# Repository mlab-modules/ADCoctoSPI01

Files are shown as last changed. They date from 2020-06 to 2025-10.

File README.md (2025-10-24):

# ADCoctoSPI01 - Octal Input High-Speed ADC Module

The ADCoctoSPI01 is an eight-channel, high-speed analog-to-digital conversion module designed for signal acquisition in imaging and similar high-speed applications. It integrates a Texas Instruments AFE5801 analog front-end (AFE), which combines eight variable-gain amplifiers (VGAs) and eight 12-bit ADCs with a sampling rate up to 65 MSPS. Data output is serialized through an LVDS interface.

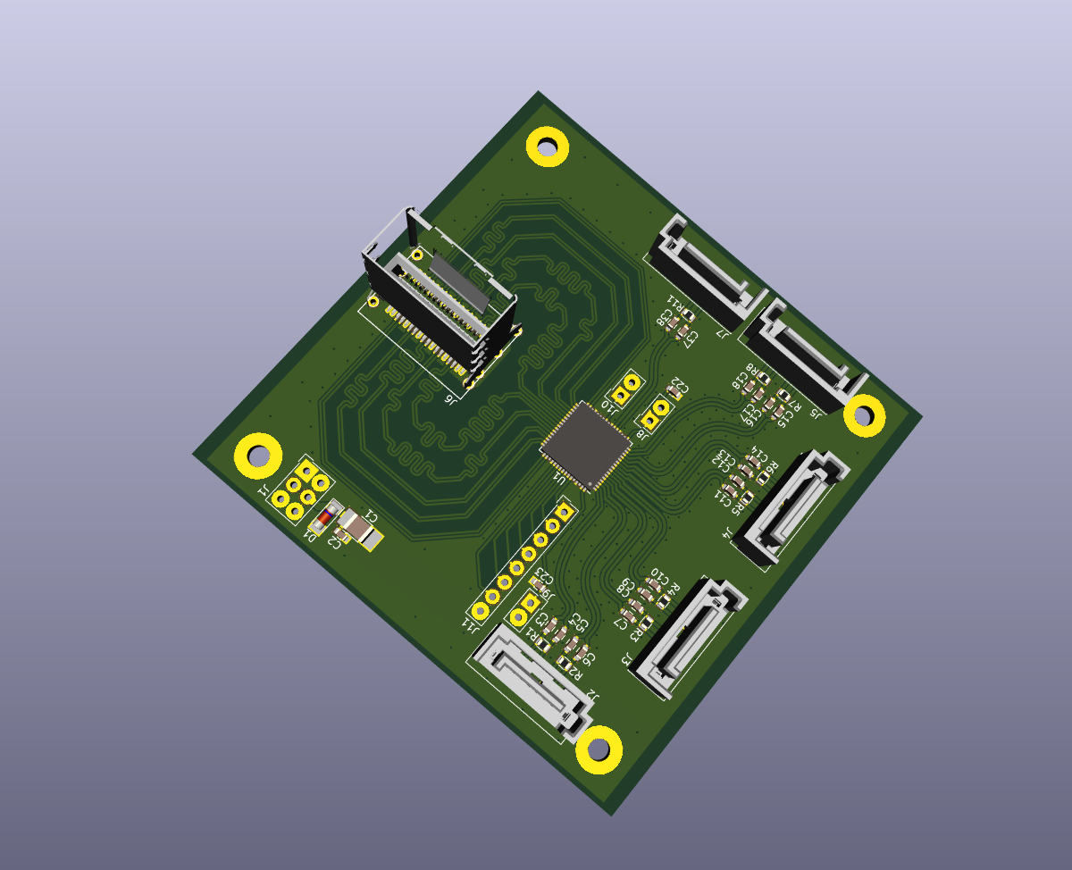
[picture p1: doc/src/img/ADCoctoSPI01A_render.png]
ADCoctoSPI01A


This module is ideally used in combination with the [MPPB01 baseboard for Parallella](https://www.mlab.cz/module/MPPB01/), which features a compatible miniSAS connector, allowing for direct integration and high-speed data transfer.

## Features

* **8 differential analog input channels**
* **Integrated AFE5801 from Texas Instruments**
  * 8x VGAs with -5 dB to 31 dB gain range
  * 8x 12-bit ADCs, up to 65 MSPS sampling rate
  * Integrated anti-aliasing filter (7.5 / 10 / 14 MHz selectable)
  * Serial LVDS output
  * SPI control interface
* **MiniSAS (SFF-8087) connector for LVDS data output**
* **Separate SPI interface for configuration and diagnostics**
* **On-board linear regulators for 1.8V and 3.3V supplies**
* **Operating voltage: 3.6 V to 5.4 V**
* **Operating temperature: -20 °C to +40 °C**

## Technical Specifications

| Parameter | Value | Description |
| --- | --- | --- |
| ADC Resolution | 12 bits | Per channel |
| Number of Channels | 8 | Differential |
| Max Sampling Rate | 65 MSPS | Per channel |
| Input Voltage Swing | 2 Vpp | Differential, max linear input range |
| VGA Gain Range | -5 dB to +31 dB | Step size: 0.125/1 dB |
| Input Referred Noise | 5.5 nV/√Hz | At VGA gain = 31 dB |
| Signal-to-Noise Ratio (SNR) | ~65 dBFS | Typical at 65 MSPS, -1 dBFS input |
| Total Harmonic Distortion (THD) | -65 dBFS | At 5 MHz input, max gain |
| Signal-to-Noise and Distortion Ratio (SINAD) | ~68 dB | |
| Antialias Filter Cutoff | 7.5 / 10 / 14 MHz | Programmable |
| Common-Mode Input Voltage (VCM) | 1.6 V | Recommended bias for AC coupling |
| Input Capacitance | 2 pF | Differential input |
| Input Resistance | 5 kΩ | To internal bias |

## Connectors

* **J1-J4**: Differential analog inputs (IN1P/M to IN8P/M) (SATA connectors)
* **J10A**: MiniSAS connector for serialized LVDS data (D1-D8, FCLK, DCLK)
* **J8**: SPI control interface (SCLK, SDATA, SDOUT, SEN, RESET, SYNC)
* **J11**: Power input (+5V, GND)

## Power Supply

* Requires a single 5V power supply.
* Onboard regulators generate 3.3V and 1.8V for AFE operation.

## AFE5801 Configuration Highlights

* **Gain Control**: SPI-controlled VGA gain, from -5 dB to 31 dB in 0.125 dB or 1 dB steps
* **Clamping and Filtering**: Optional signal clamping and integrated third-order low-pass filter
* **Sampling Clock**: Differential clock input (LVDS/PECL supported)
* **LVDS Output**: Serialized outputs for each channel (D1-D8), frame clock (FCLK), and data clock (DCLK)

## Typical Applications

* Medical ultrasound systems
* Non-destructive testing
* High-speed data acquisition
* Multichannel signal digitization in SDR receivers

## References

* [AFE5801 Datasheet](https://www.ti.com/product/AFE5801)
* Other compatible AFEs: AFE5805, AFE5809 (with differing performance and power specs)

## Notes

* Only the AFE5801 is populated by default; board supports footprint-compatible variants (AFE5803, AFE5804 etc.).
* For optimal performance, ensure proper analog signal termination and impedance matching on all differential inputs.
* Follow ESD precautions during handling.

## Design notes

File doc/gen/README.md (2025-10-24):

# PCB

Board size: 70.61x70.61 mm (2.78x2.78 inches)

- This is the size of the rectangle that contains the board
- Thickness: 1.6 mm (63 mils)
- Material: FR4
- Finish: None
- Layers: 2
- Copper thickness: 35 µm

Solder mask: TOP / BOTTOM

- Color: Green

Silk screen: TOP / BOTTOM

- Color: White

Stackup:

| Name | Type | Color | Thickness [µm]| Material | Er | Loss tan |
|---|---|---|---|---|---|---|
| F.SilkS | Top Silk Screen | | | | | |
| F.Paste | Top Solder Paste | | | | | |
| F.Mask | Top Solder Mask | | 10 | | | |
| F.Cu | copper | | 35 | | | |
| dielectric 1 | core | | 1510 | FR4 | 4.5 | 0.020 |
| B.Cu | copper | | 35 | | | |
| B.Mask | Bottom Solder Mask | | 10 | | | |
| B.Paste | Bottom Solder Paste  | | | | | |
| B.SilkS | Bottom Silk Screen | | | | | |

# Important sizes

Clearance: 0.2 mm (8 mils)

Track width: 0.2 mm (8 mils)

- By design rules: 0.15 mm (6 mils)

Drill: 0.3 mm (12 mils)

- Vias: 0.5 mm (20 mils) [Design: 0.3 mm (12 mils)]
- Pads: 0.3 mm (12 mils)
- The above values are real drill sizes, they add 0.1 mm (4 mils) to plated holes (PTH)

Via: 0.75/0.4 mm (30/16 mils)

- By design rules: 0.4/0.2 mm (16/8 mils)
- Micro via: yes [0.2/0.1 mm (8/4 mils)]
- Buried/blind via: yes
- Total: 263 (thru: 263 buried/blind: 0 micro: 0)

Outer Annular Ring: 0.05 mm (2 mils)

- By design rules: 0.05 mm (2 mils)

Eurocircuits class: 6F
- Using min drill 0.15 mm for an OAR of 0.13 mm

# General stats

Components count: (SMD/THT)

- Top: 38/14 (SMD + THT)
- Bottom: 27/0 (SMD)

Defined tracks:

- 0.2 mm (8 mils)
- 0.3 mm (12 mils)
- 0.4 mm (16 mils)
- 0.5 mm (20 mils)
- 1.0 mm (39 mils)

Used tracks:

- 0.2 mm (8 mils) (10) defined: yes
- 0.25 mm (10 mils) (3) defined: no
- 0.28 mm (11 mils) (2504) defined: no
- 0.3 mm (12 mils) (167) defined: yes
- 0.4 mm (16 mils) (662) defined: yes
- 0.5 mm (20 mils) (45) defined: yes
- 0.8 mm (31 mils) (7) defined: no
- 1.0 mm (39 mils) (15) defined: yes

Defined vias:

Used vias:

- 0.75/0.4 mm (30/16 mils) (Count: 229, Aspect: 2.1 A) defined: no
- 0.8/0.4 mm (31/16 mils) (Count: 34, Aspect: 2.0 A) defined: no

Holes (excluding vias):

- 0.2 mm (8 mils) (45)
- 0.74 mm (29 mils) (35)
- 0.8 mm (31 mils) (8)
- 0.89 mm (35 mils) (20)
- 1.35 mm (53 mils) (10)
- 1.55 mm (61 mils) (2)
- 3.0 mm (118 mils) (4)

Oval holes:

Drill tools (including vias and computing adjusts and rounding):

- 0.3 mm (12 mils) (45)
- 0.5 mm (20 mils) (263)
- 0.85 mm (33 mils) (35)
- 0.9 mm (35 mils) (8)
- 1.0 mm (39 mils) (20)
- 1.45 mm (57 mils) (10)
- 1.55 mm (61 mils) (2)
- 3.1 mm (122 mils) (4)

Solder paste stats:

Using a paste with 87.75 % alloy, that has an specific gravity for the alloy of 7.4 g/cm³
and 1.0 g/cm³ for the flux. This paste has an specific gravity of  4.15 g/cm³.

The stencil thickness is  0.12 mm.

| Side | Pads with paste | Area [mm²] | Paste [g] |
|---|---|---|---|
| Top | 172 | 104.12 | 0.52 |
| Bottom | 58 | 77.69 | 0.39 |
| Total  | 230 | 181.81 | 0.90 |

Note: this is just an approximation to the theoretical value. Margins of the solder mask and waste aren't computed.

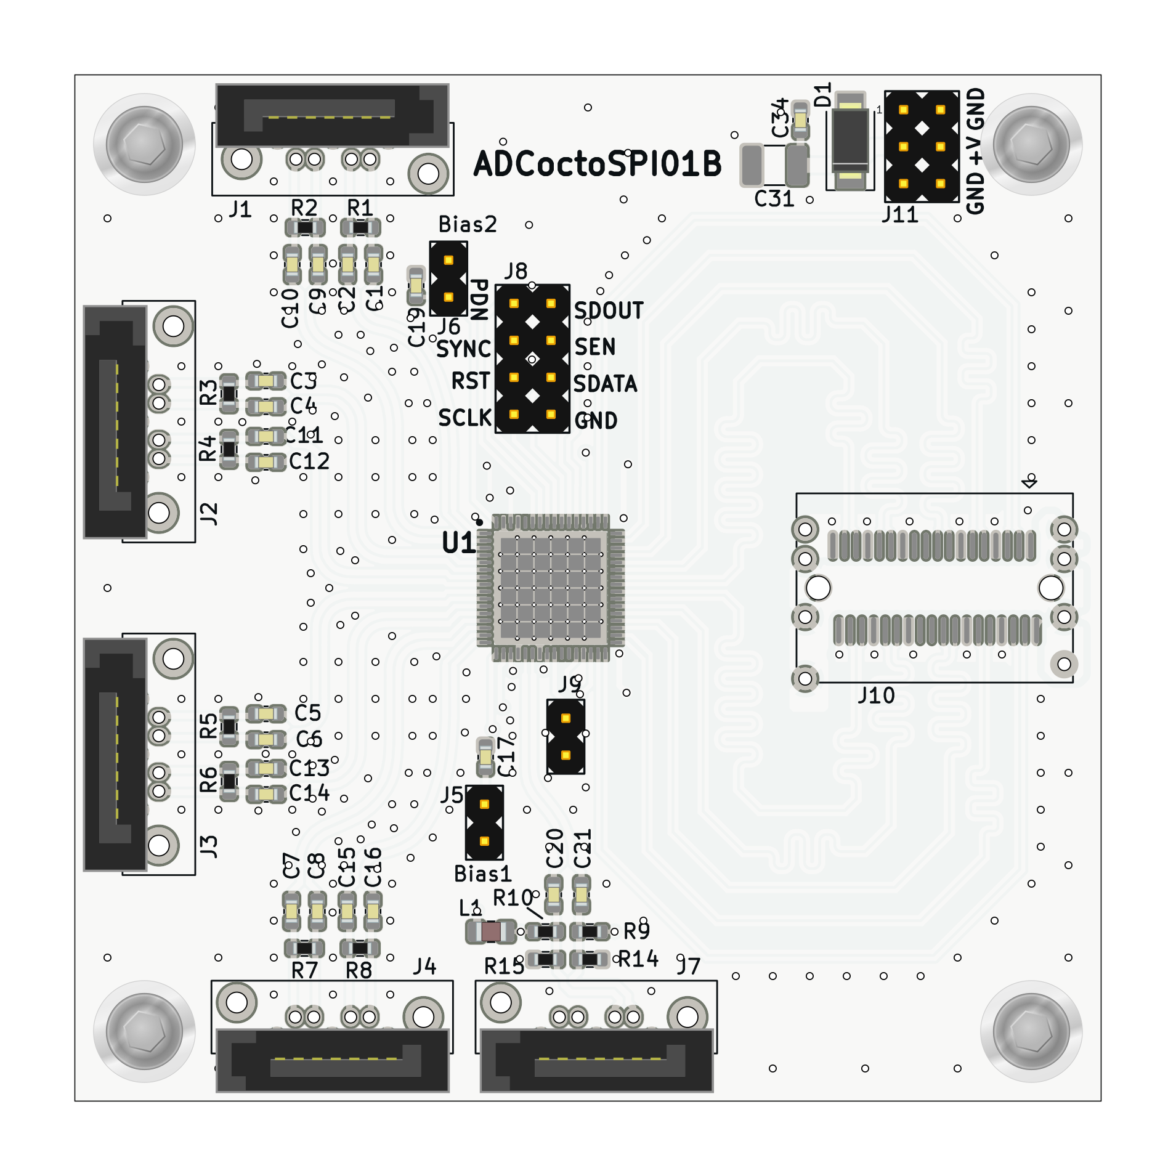
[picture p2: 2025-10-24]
doc/gen/img/ADCoctoSPI01-top.png

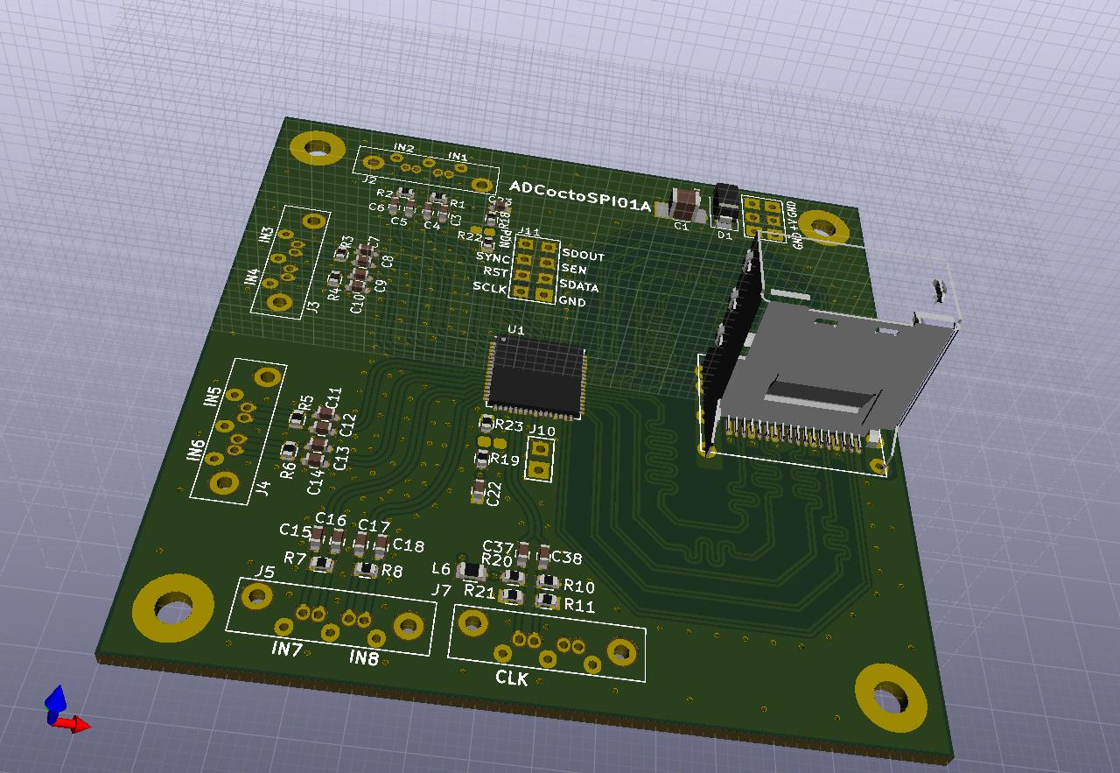
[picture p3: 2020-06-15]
doc/src/img/ADCoctoSPI01A.jpg

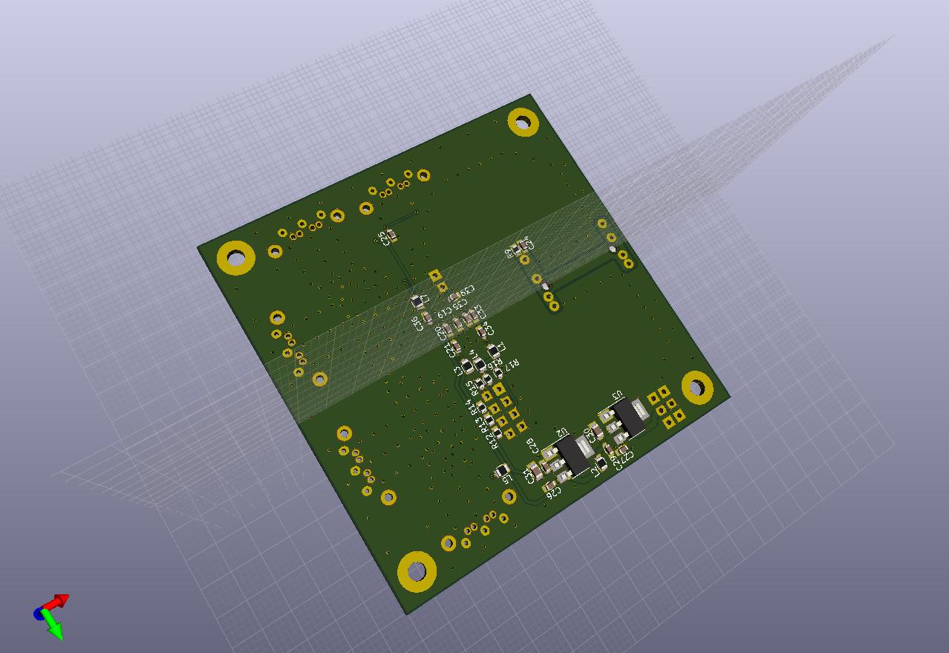
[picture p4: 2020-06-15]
doc/src/img/bottom.jpg

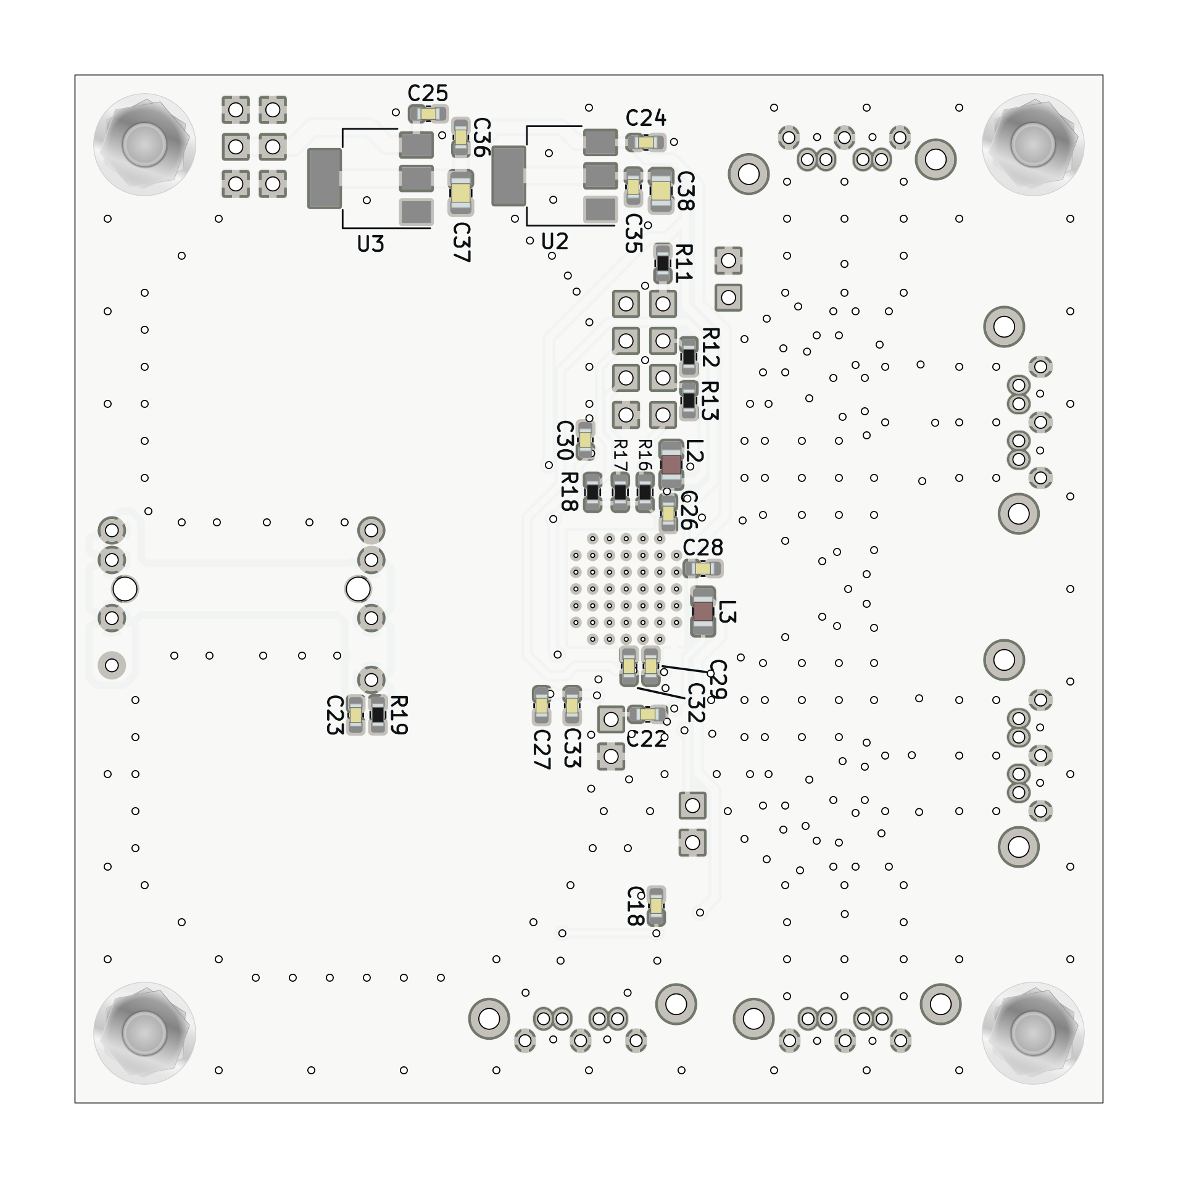
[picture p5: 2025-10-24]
doc/gen/img/ADCoctoSPI01-bottom.png

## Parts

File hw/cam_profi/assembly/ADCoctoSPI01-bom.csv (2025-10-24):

Component | Description | Part | References | Value | Footprint | Quantity Per PCB | Datasheet | ust_id
1 |  | C_Small-device | C1C2C3C4C5C6C7C8C9C10C11C12C13C14C15C16 | 10nF | C_0603_1608Metric | 16 |  | 5c70984812875079b91f8bef
2 |  | C_Small-device | C17C18C19C20C21C22C23C24C25C26C27C28C29C30C32C33C34C35C36 | 100nF | C_0603_1608Metric | 19 |  | 5c70984812875079b91f8bf2
3 |  | C_Small-device | C37C38 | 10uF | C_0805_2012Metric | 2 |  | 5c70984812875079b91f8bbd
4 |  | C_Small-device | C31 | 100uF/6V3 | C_1210_3225Metric_Pad1.33x2.70mm_HandSolder | 1 | https://www.tme.eu/sk/katalog/ | 5c70984812875079b91f8bbb
5 |  | D_Small-device | D1 | M4 | D_SMA | 1 |  | 5c70984512875079b91f88ac
6 |  | HEADER_2x03_PARALLEL-MLAB_HEADER | J11 | +5V | Straight_2x03 | 1
7 |  | HEADER_1x02-MLAB_HEADER | J5J6J9 | HEADER_1x02 | Straight_1x02 | 3
8 |  | HEADER_2x04-MLAB_HEADER | J8 | HEADER_2x04 | Straight_2x04 | 1
9 |  | SAS_mini_1888174-MLAB_CONNECTORS | J10 | SAS_mini_1888174 | SAS-mini_TEConnectivity_1888174_Vertical | 1 |  | 624ede60592c2d62176d5a96
10 |  | SATA7-67491-1030-MLAB_CONNECTORS | J1J2J3J4J7 | SATA7-67491-1030 | SATA-7_THT_VERT_2 | 5 |  | 5c70984712875079b91f8a7b
11 |  | L-device | L1L2L3 | BLM21PG300SN1D | L_0805_2012Metric_Pad1.15x1.40mm_HandSolder | 3 |  | 5c70984412875079b91f87fd
12 |  | R-device | R14R15 | 82 | R_0603_1608Metric | 2 |  | 5c70984512875079b91f8955
13 |  | R-device | R1R2R3R4R5R6R7R8R19 | 100 | R_0603_1608Metric | 9 |  | 5c70984512875079b91f8956
14 |  | R-device | R9R10 | 130 | R_0603_1608Metric | 2 |  | 5cd08b17128750448e4542b1
15 |  | R-device | R11R12R13R16R17R18 | 10k | R_0603_1608Metric | 6 |  | 5c70984512875079b91f8962
16 |  | AFE5801-DENGS_lib | U1 | AFE5801 | VQFN-64_9.15x9.15mm_EP_7.5x7.5mm | 1 | https://www.ti.com/lit/ds/symlink/afe5801.pdf | 624edf21592c2d62176d5abc
17 |  | LD1117S18TR-RESCUE-ADCoctoSPI01A | U2 | LM1117MP-1,8/NO | SOT-223-3_TabPin2 | 1 |  | 5c70984712875079b91f8af6
18 |  | LD1117S33TR-RESCUE-ADCoctoSPI01A | U3 | LM1117MP-3,3/NO | SOT-223-3_TabPin2 | 1 |  | 5c70984712875079b91f8af9

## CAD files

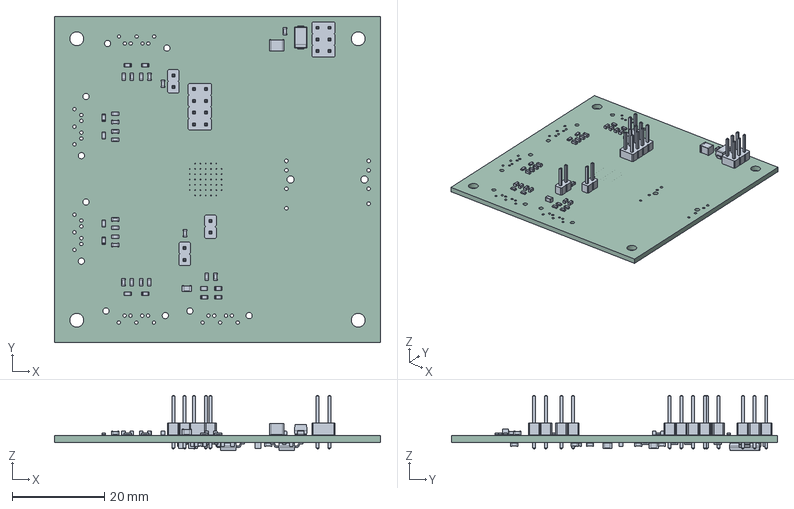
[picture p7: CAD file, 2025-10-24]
doc/gen/ADCoctoSPI01.step
70.6 x 70.6 x 11.9 mm
C_1210_3225Metric
D_SMA
R_0603_1608Metric x 19
C_0603_1608Metric x 35
PinHeader_2x04_P2.54mm_Vertical
PinHeader_1x02_P2.54mm_Vertical x 3
PinHeader_2x03_P2.54mm_Vertical
L_0805_2012Metric x 3
SOT-223 x 2
C_0805_2012Metric x 2
kibot_9znxb3cl_PCB

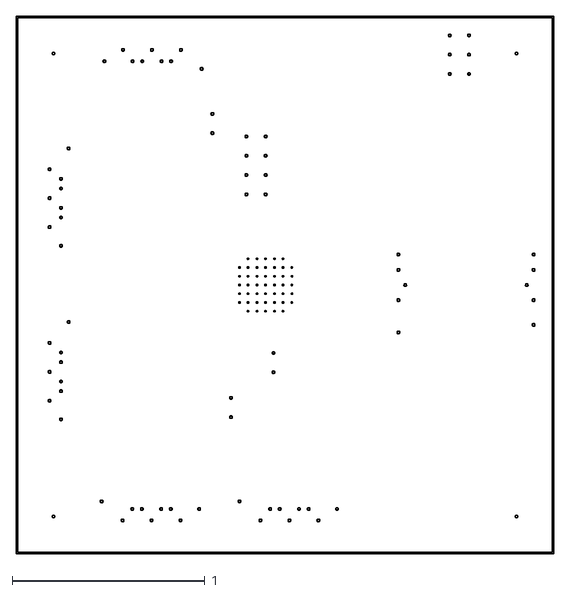
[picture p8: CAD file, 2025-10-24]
doc/gen/dxf/ADCoctoSPI01-Edge_Cuts.dxf
2.79 x 2.79

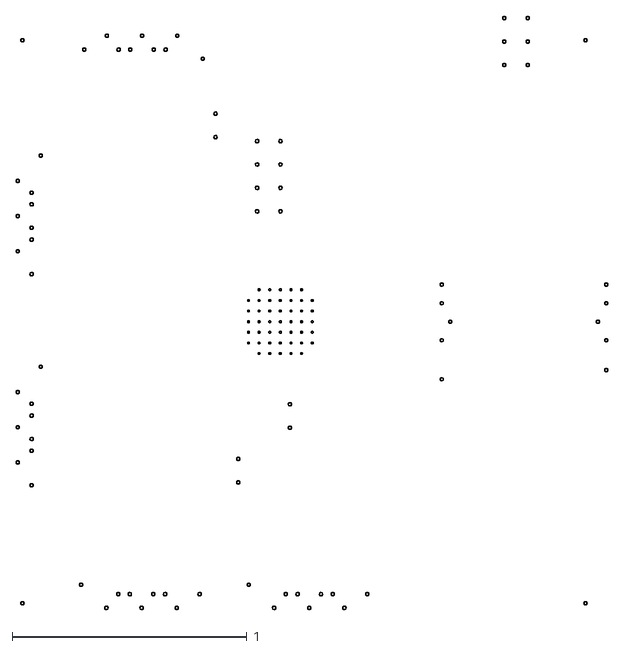
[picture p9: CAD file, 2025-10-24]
doc/gen/dxf/ADCoctoSPI01-User_Eco1.dxf
2.52 x 2.53

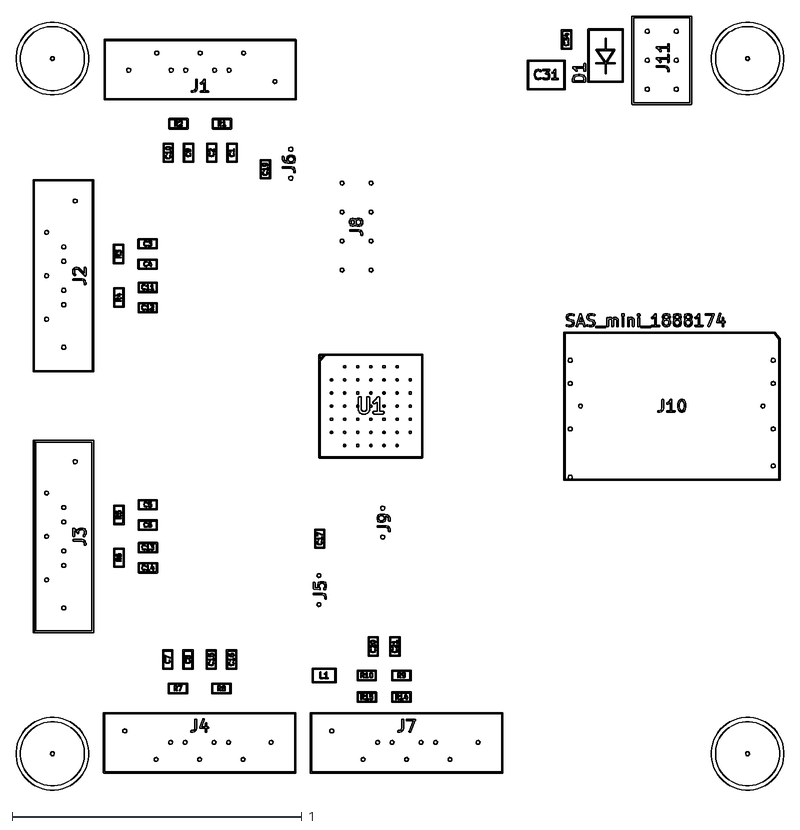
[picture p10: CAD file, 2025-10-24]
doc/gen/dxf/ADCoctoSPI01-F_Fab.dxf
2.65 x 2.67

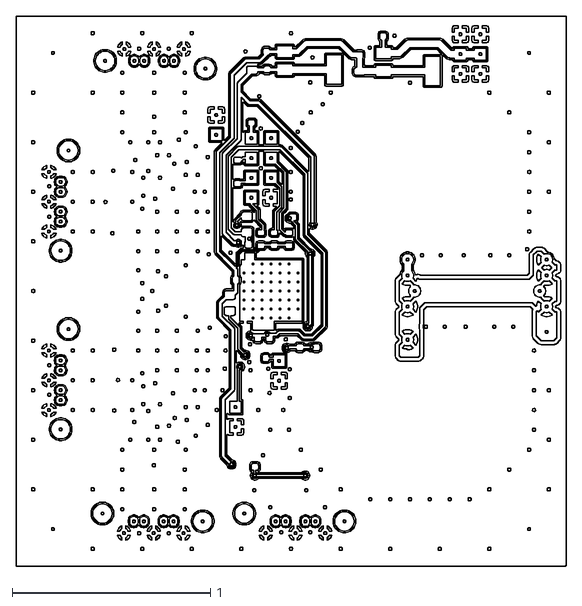
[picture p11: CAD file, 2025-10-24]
doc/gen/dxf/ADCoctoSPI01-B_Cu.dxf
2.77 x 2.77

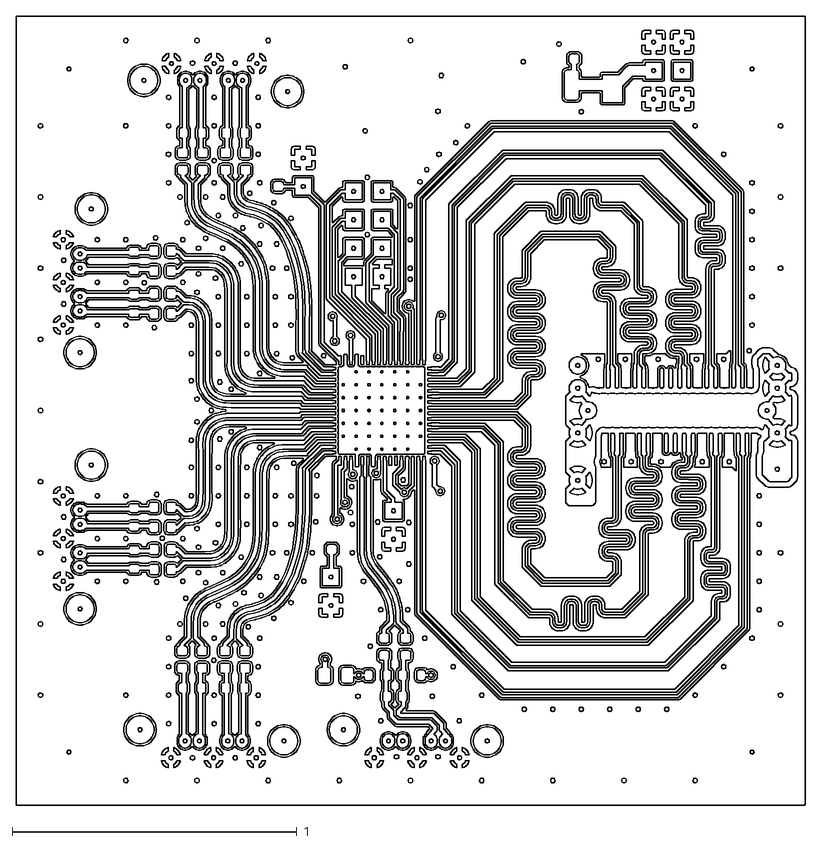
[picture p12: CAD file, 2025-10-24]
doc/gen/dxf/ADCoctoSPI01-F_Cu.dxf
2.77 x 2.77

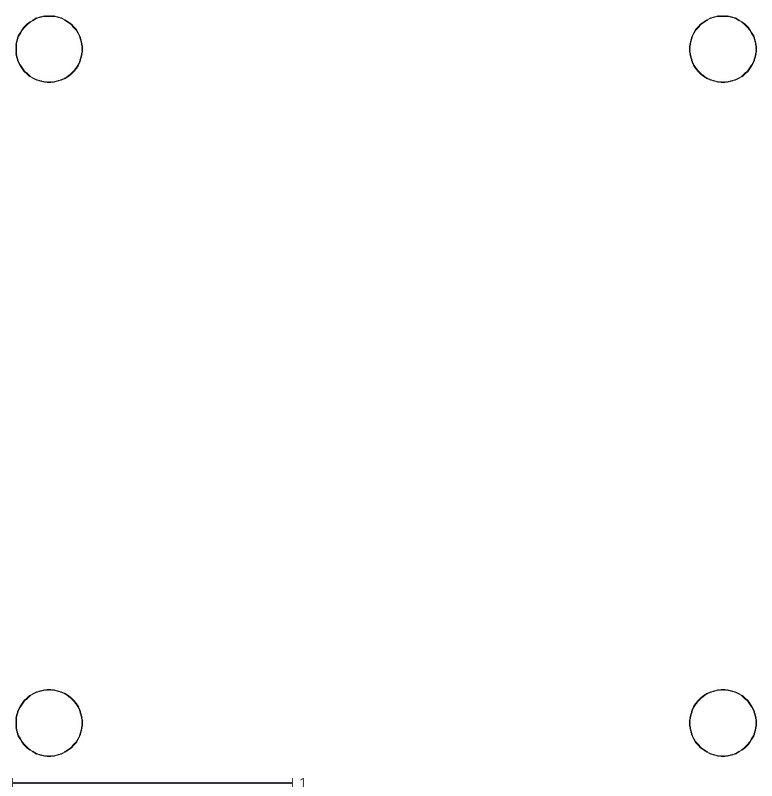
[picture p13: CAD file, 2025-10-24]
doc/gen/dxf/ADCoctoSPI01-B_Adhesive.dxf
2.64 x 2.64

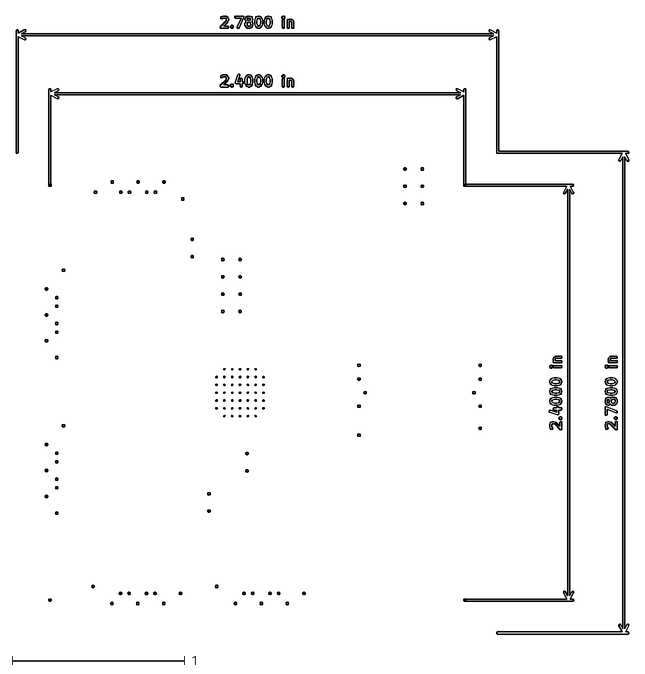
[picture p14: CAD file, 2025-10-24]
doc/gen/dxf/ADCoctoSPI01-User_Drawings.dxf
3.54 x 3.58

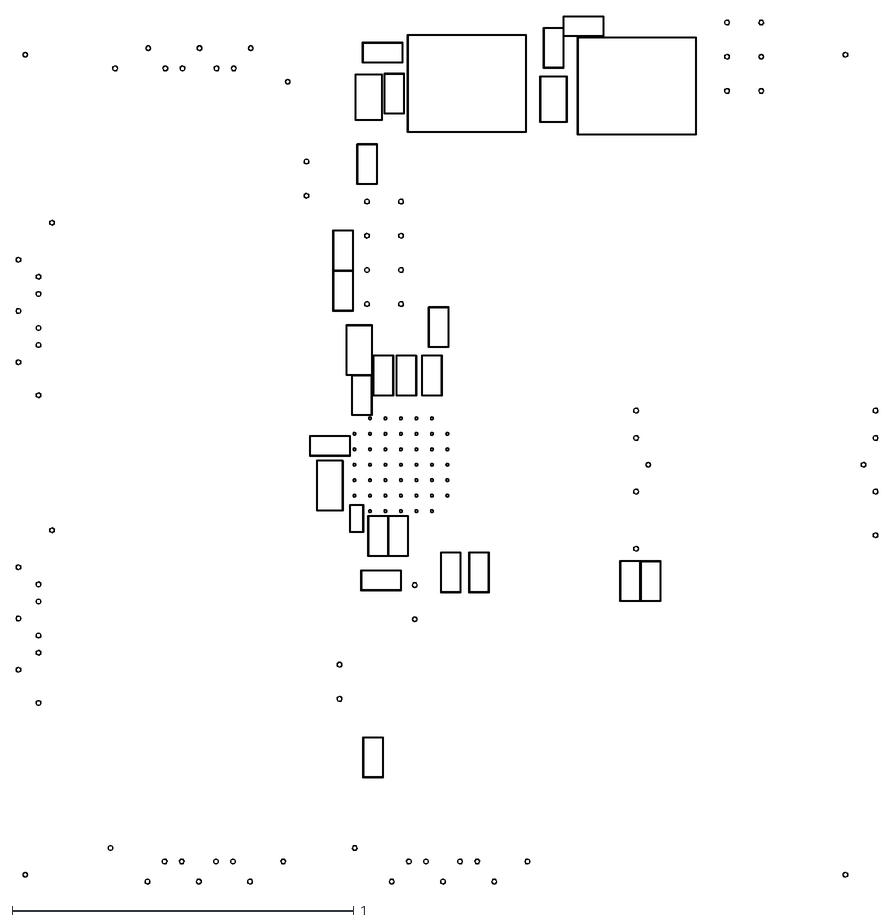
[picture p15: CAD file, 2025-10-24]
doc/gen/dxf/ADCoctoSPI01-B_Courtyard.dxf
2.52 x 2.54

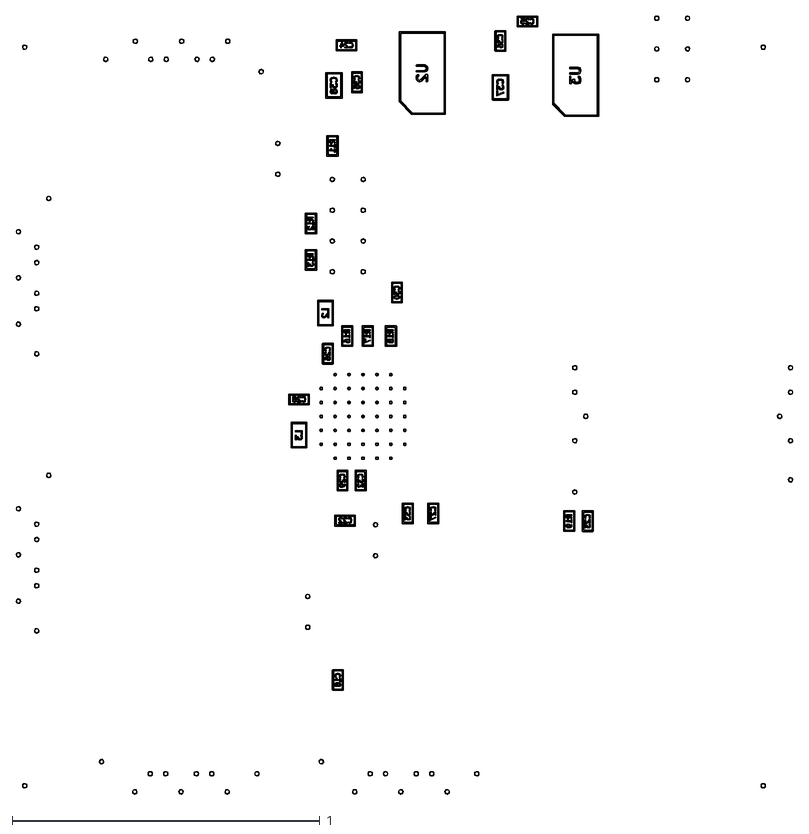
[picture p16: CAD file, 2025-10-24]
doc/gen/dxf/ADCoctoSPI01-B_Fab.dxf
2.52 x 2.53

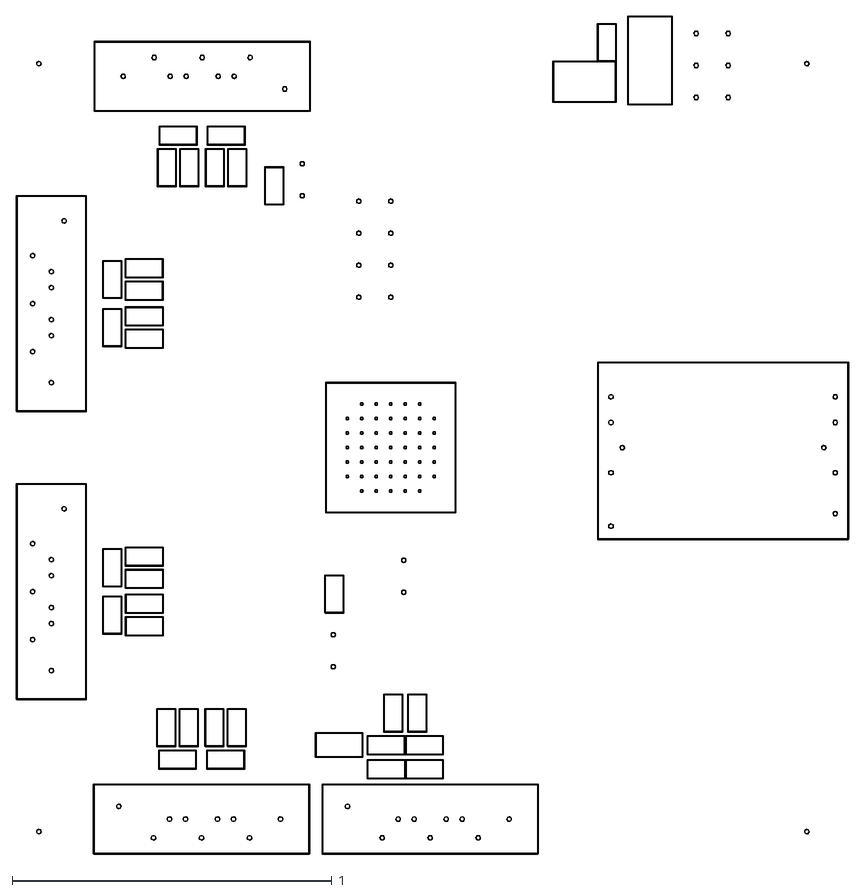
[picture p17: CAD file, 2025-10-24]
doc/gen/dxf/ADCoctoSPI01-F_Courtyard.dxf
2.60 x 2.62

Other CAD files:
doc/gen/dxf/ADCoctoSPI01-B_Mask.dxf
doc/gen/dxf/ADCoctoSPI01-B_Paste.dxf
doc/gen/dxf/ADCoctoSPI01-B_Silkscreen.dxf
doc/gen/dxf/ADCoctoSPI01-F_Mask.dxf
doc/gen/dxf/ADCoctoSPI01-F_Paste.dxf
doc/gen/dxf/ADCoctoSPI01-F_Silkscreen.dxf

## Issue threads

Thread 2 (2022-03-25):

mini-SAS connector alingment

kaklik, 2022-03-25:
Vypadá to, že stejně jako https://github.com/mlab-modules/MPPB01/issues/3 má i tento modul problém se špatně zarovnanými ploškami u mini-SAS konektoru.

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

kaklik, 2022-03-25:
Vyřešeno změnou na KiCAD upstream verzi footprintu a jeho opravou.

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

Closed 2022-03-25.

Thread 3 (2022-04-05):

Wrong footprint of ADC

kaklik, 2022-04-05:
@ChroustJan  přišel na to, že pouzdro pod ADC nerespektuje základní požadavky výrobce na footprint. [viz datasheet strana 46.](https://www.ti.com/lit/ds/symlink/afe5801.pdf)
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

Problém je poměrně zásadní, protože zřjemě zbytečně zvyšuje teplotu a šum ADC.

Společně s tím stávající layout narušuje pravidlo absence jiných signálů než GND přímo pod pouzdrem ADC.

kaklik, 2022-05-25:
Tohle je snad již vyřešené.

Closed 2022-05-25.

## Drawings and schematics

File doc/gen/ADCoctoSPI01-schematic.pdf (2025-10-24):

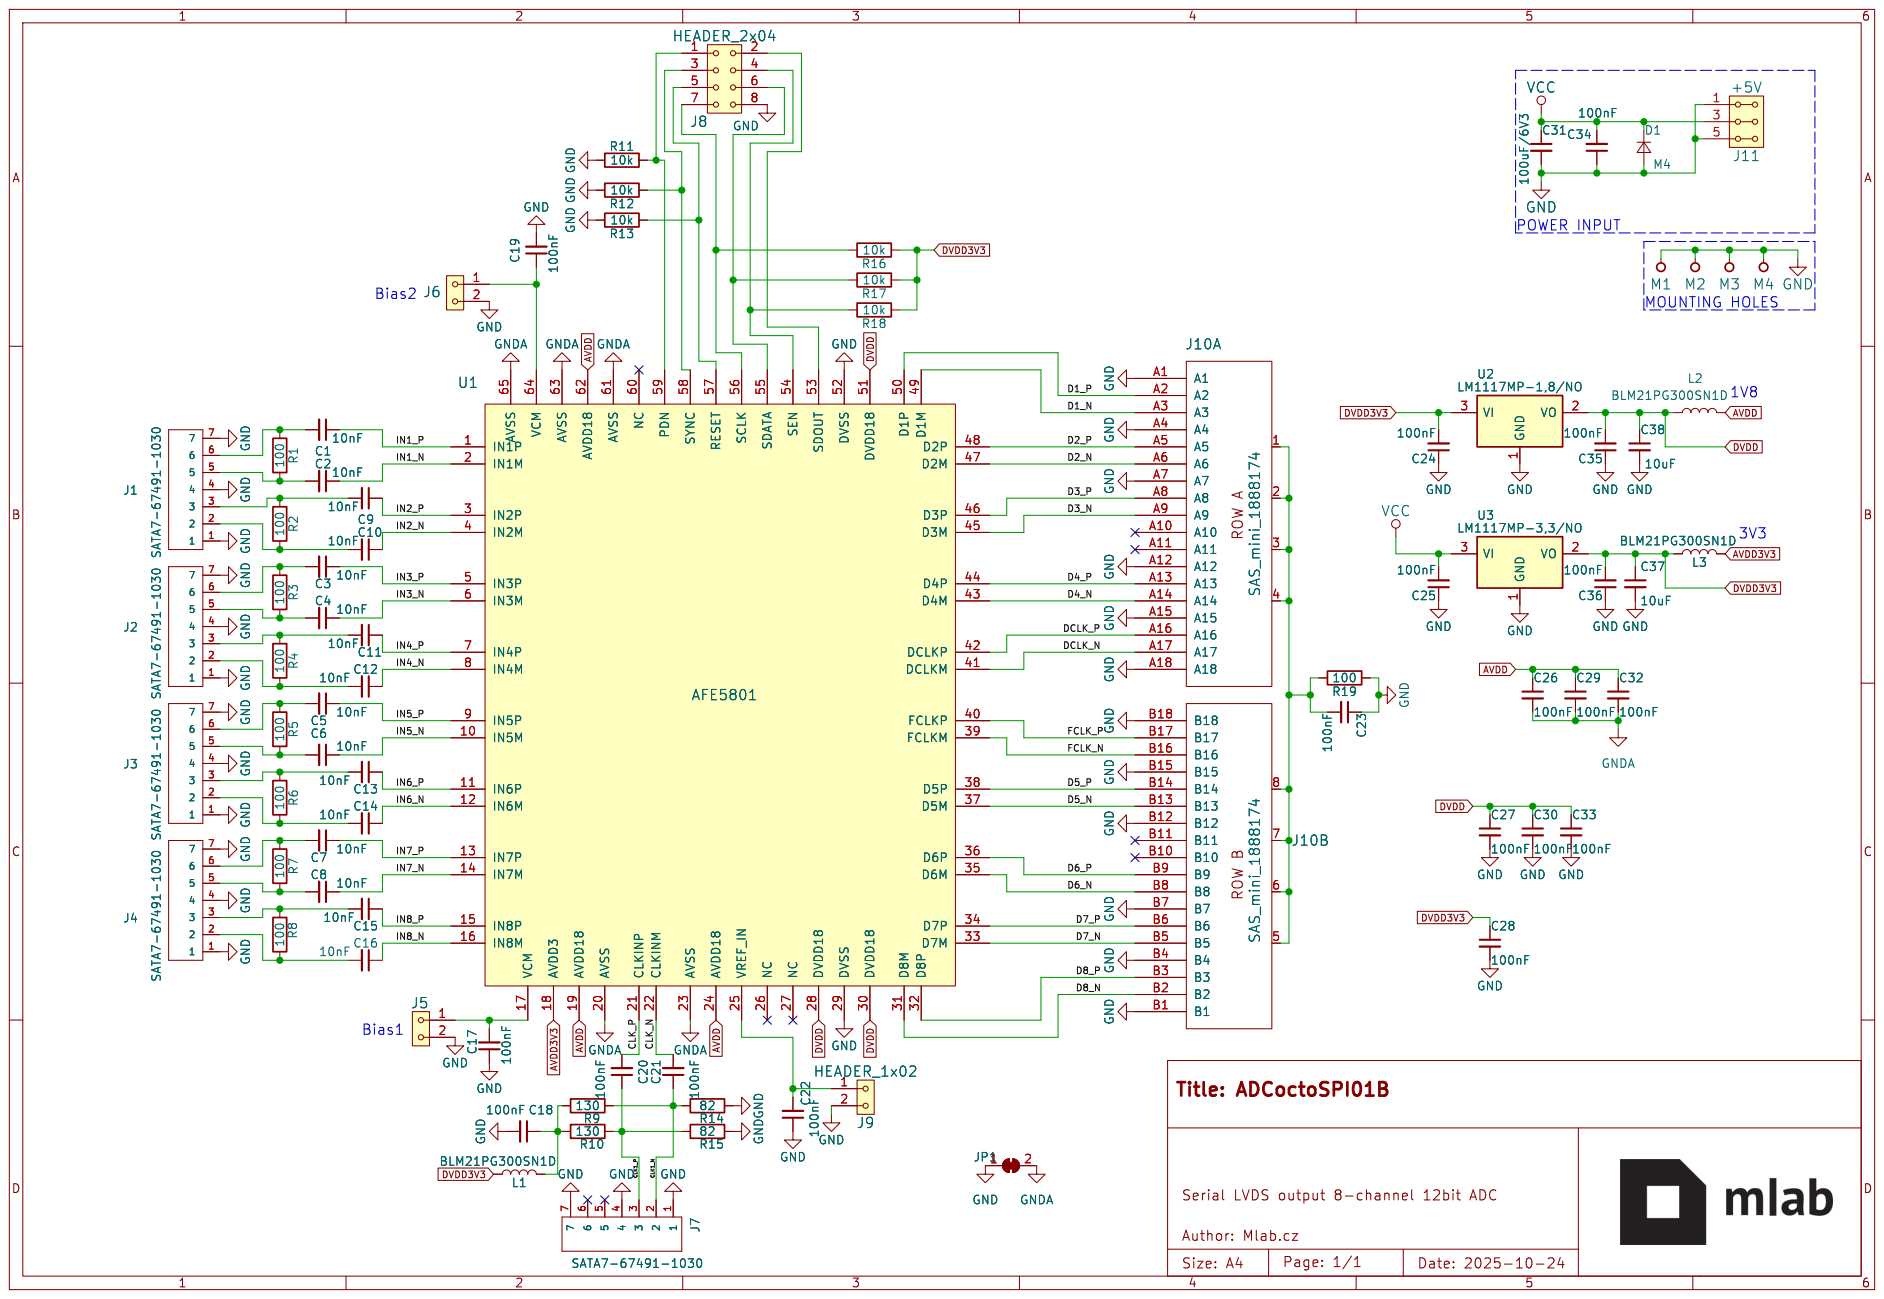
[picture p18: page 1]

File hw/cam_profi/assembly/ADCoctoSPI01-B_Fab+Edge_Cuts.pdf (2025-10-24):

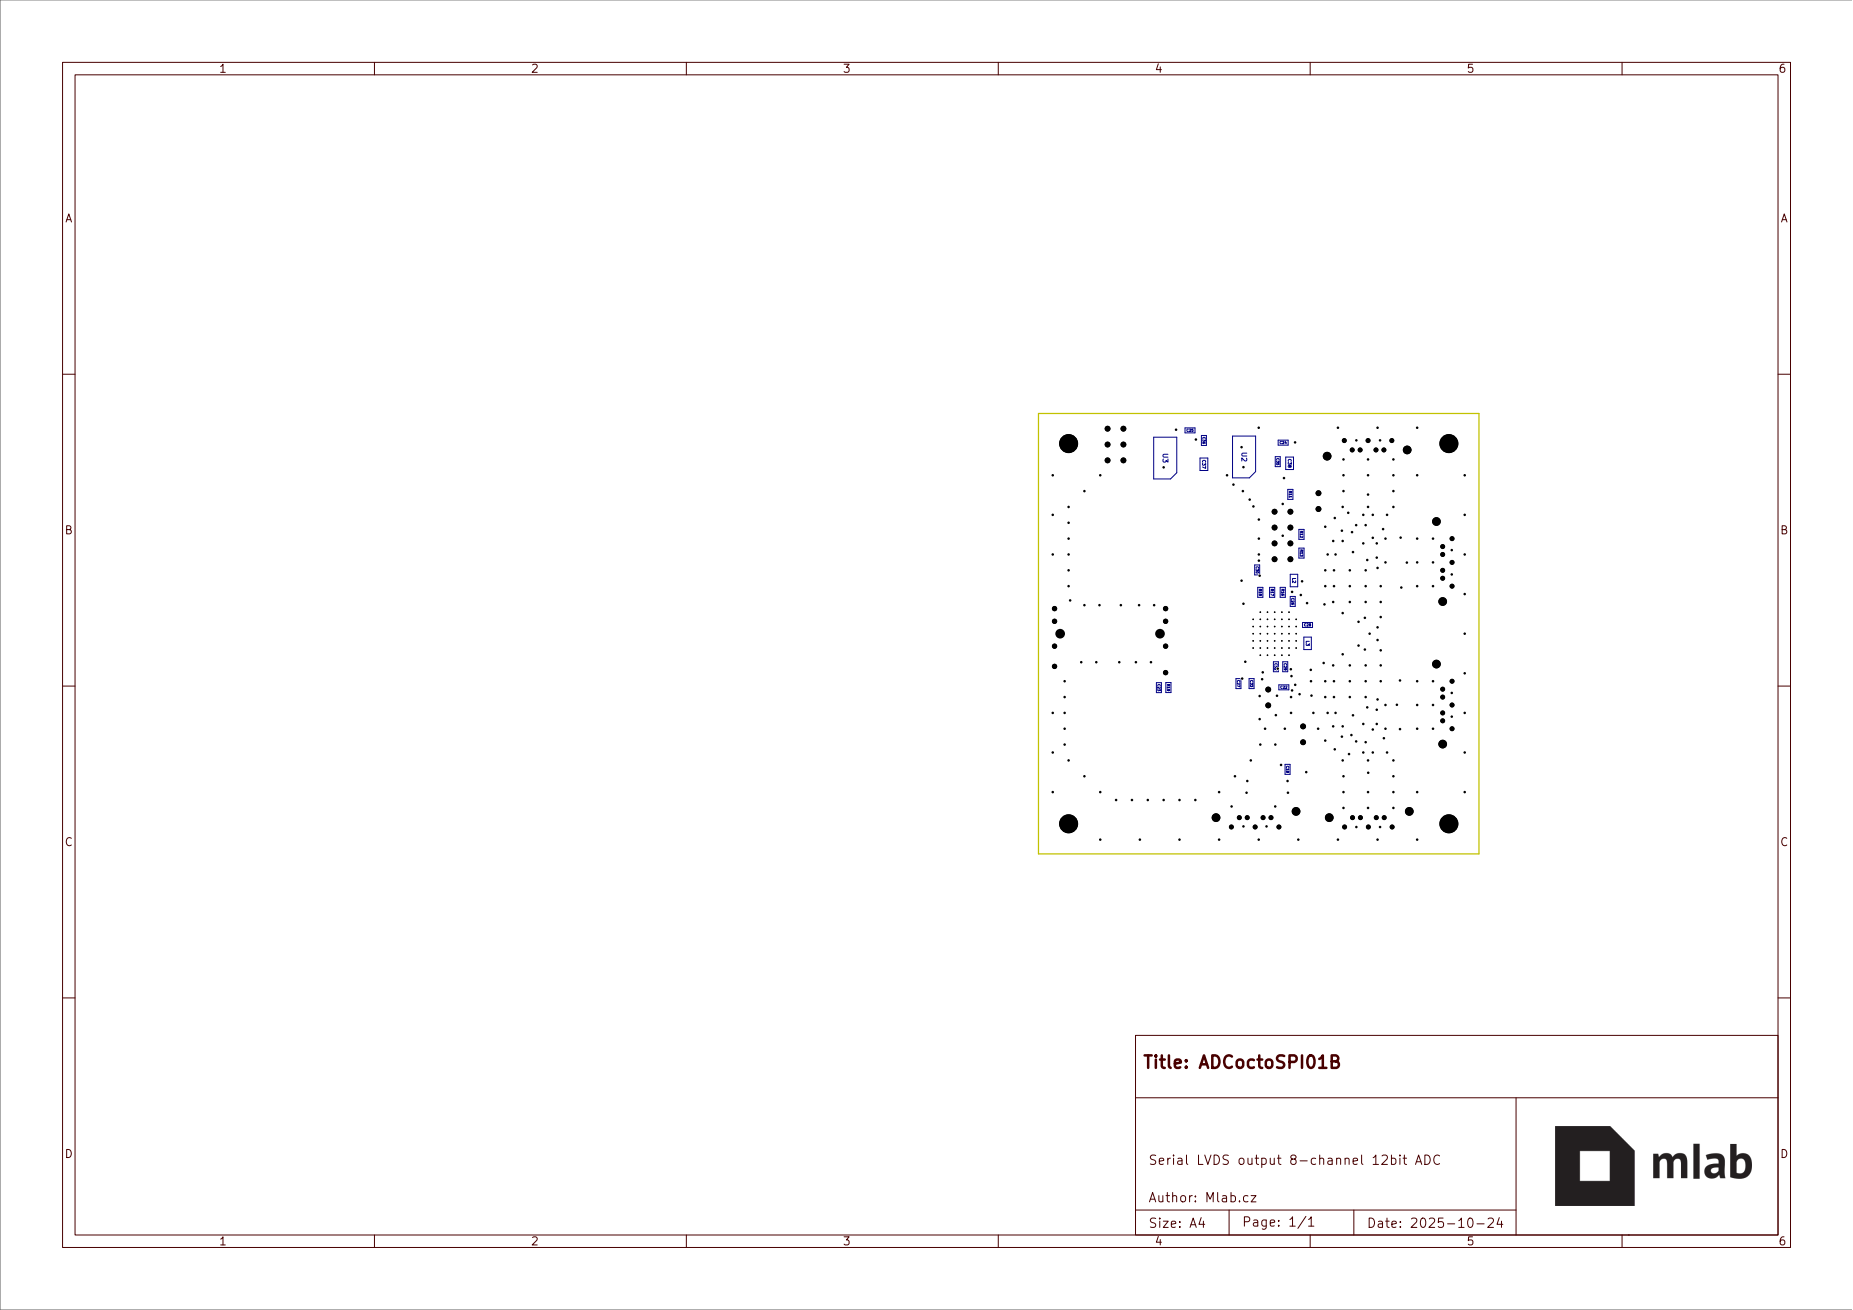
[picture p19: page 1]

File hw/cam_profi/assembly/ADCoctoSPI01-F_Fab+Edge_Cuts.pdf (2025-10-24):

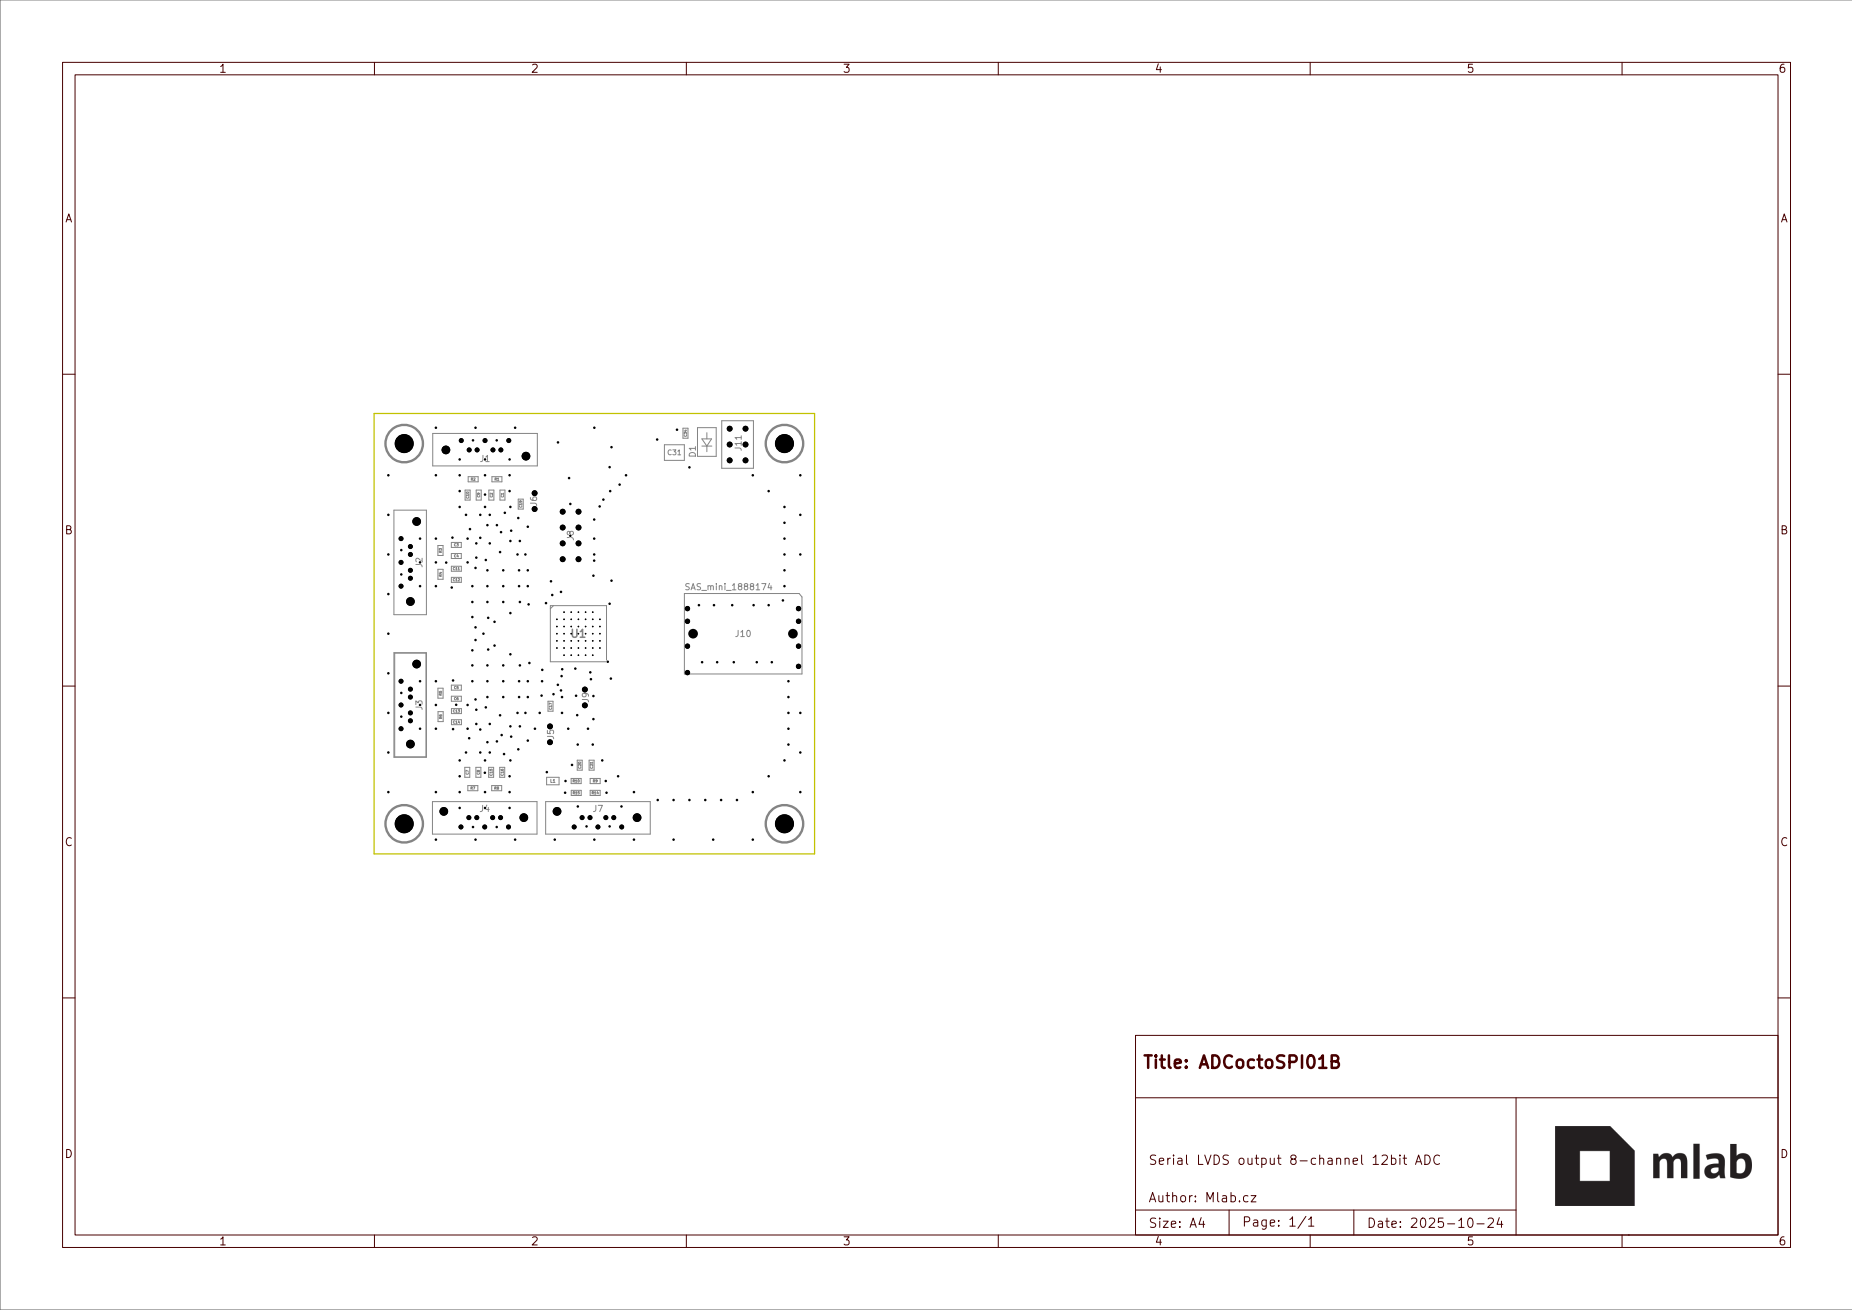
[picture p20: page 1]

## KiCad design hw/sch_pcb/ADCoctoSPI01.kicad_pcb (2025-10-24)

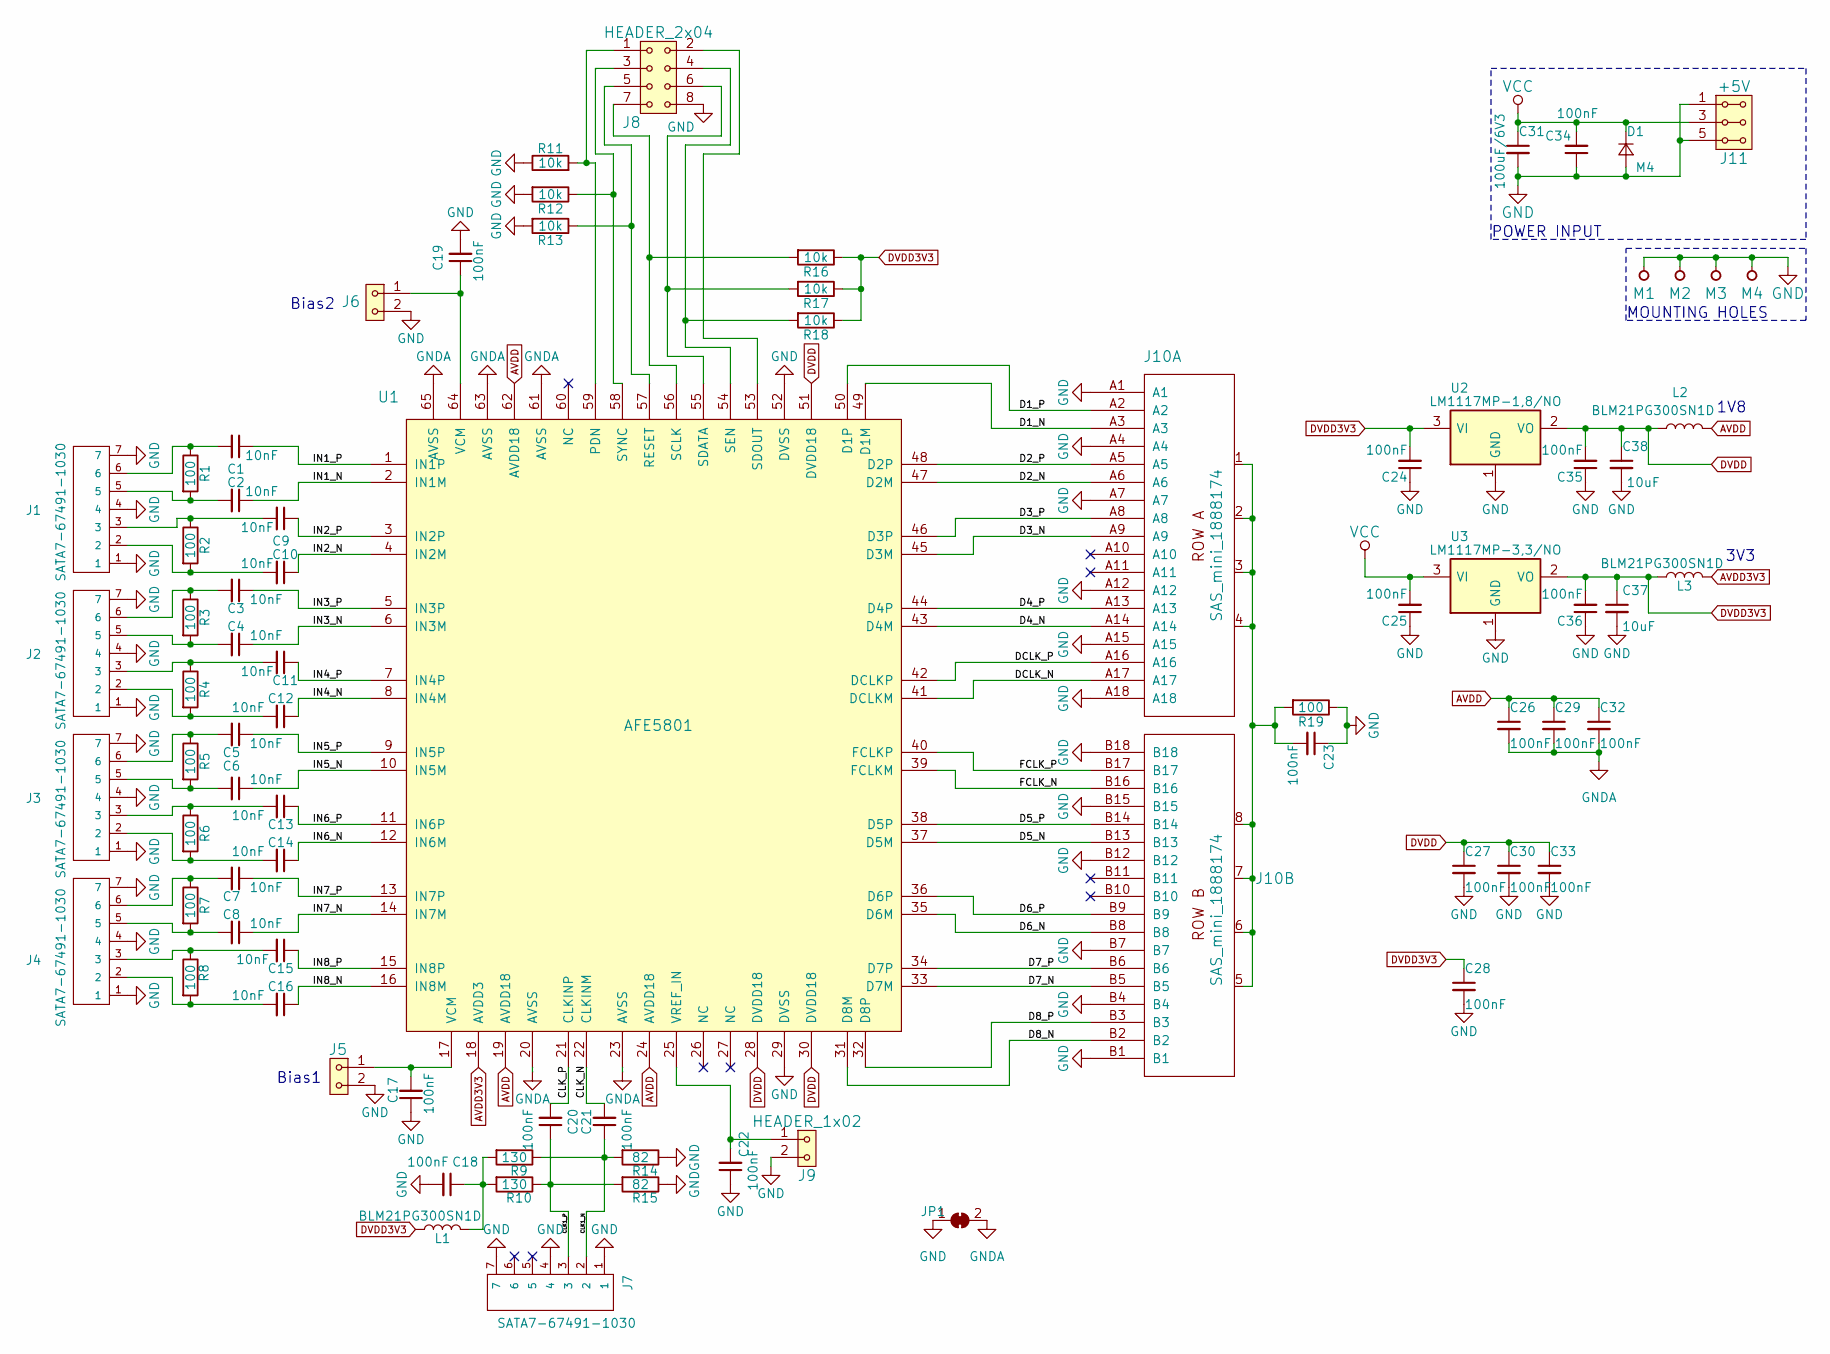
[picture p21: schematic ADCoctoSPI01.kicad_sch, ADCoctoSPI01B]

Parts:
C1, C2, C3, C4, C5, C6, C7, C8, C9, C10, C11, C12, C13, C14, C15, C16: 10nF; C_0603_1608Metric
C17, C18, C19, C20, C21, C22, C23, C24, C25, C26, C27, C28, C29, C30, C32, C33, C34, C35, C36: 100nF; C_0603_1608Metric
C31: 100uF/6V3; C_1210_3225Metric_Pad1.33x2.70mm_HandSolder
C37, C38: 10uF; C_0805_2012Metric
D1: M4; D_SMA
J1, J2, J3, J4, J7: SATA7-67491-1030; SATA-7_THT_VERT_2
J5, J6, J9: HEADER_1x02; Straight_1x02
J8: HEADER_2x04; Straight_2x04
J10: SAS_mini_1888174; SAS-mini_TEConnectivity_1888174_Vertical
J11: +5V; Straight_2x03
JP1: SolderJumper_2_Bridged; NetTie-2_SMD_Pad0.5mm
L1, L2, L3: BLM21PG300SN1D; L_0805_2012Metric_Pad1.15x1.40mm_HandSolder
M1, M2, M3, M4: HOLE; MountingHole_3mm
R1, R2, R3, R4, R5, R6, R7, R8, R19: 100; R_0603_1608Metric
R9, R10: 130; R_0603_1608Metric
R11, R12, R13, R16, R17, R18: 10k; R_0603_1608Metric
R14, R15: 82; R_0603_1608Metric
U1: AFE5801; VQFN-64_9.15x9.15mm_EP_7.5x7.5mm
U2: LM1117MP-1,8/NO; SOT-223-3_TabPin2
U3: LM1117MP-3,3/NO; SOT-223-3_TabPin2

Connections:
/CLK1_N: C21.1, J7.2, R9.1, R14.2
/CLK1_P: C20.1, J7.3, R10.1, R15.2
/CLK_N: C21.2, U1.22 (CLKINM)
/CLK_P: C20.2, U1.21 (CLKINP)
/D1_N: J10.A3, U1.49 (D1M)
/D1_P: J10.A2, U1.50 (D1P)
/D2_N: J10.A6, U1.47 (D2M)
/D2_P: J10.A5, U1.48 (D2P)
/D3_N: J10.A9, U1.45 (D3M)
/D3_P: J10.A8, U1.46 (D3P)
/D4_N: J10.A14, U1.43 (D4M)
/D4_P: J10.A13, U1.44 (D4P)
/D5_N: J10.B13, U1.37 (D5M)
/D5_P: J10.B14, U1.38 (D5P)
/D6_N: J10.B8, U1.35 (D6M)
/D6_P: J10.B9, U1.36 (D6P)
/D7_N: J10.B5, U1.33 (D7M)
/D7_P: J10.B6, U1.34 (D7P)
/D8_N: J10.B2, U1.31 (D8M)
/D8_P: J10.B3, U1.32 (D8P)
/DCLK_N: J10.A17, U1.41 (DCLKM)
/DCLK_P: J10.A16, U1.42 (DCLKP)
/FCLK_N: J10.B16, U1.39 (FCLKM)
/FCLK_P: J10.B17, U1.40 (FCLKP)
/IN1_N: C2.1, U1.2 (IN1M)
/IN1_P: C1.1, U1.1 (IN1P)
/IN2_N: C10.1, U1.4 (IN2M)
/IN2_P: C9.1, U1.3 (IN2P)
/IN3_N: C4.1, U1.6 (IN3M)
/IN3_P: C3.1, U1.5 (IN3P)
/IN4_N: C12.1, U1.8 (IN4M)
/IN4_P: C11.1, U1.7 (IN4P)
/IN5_N: C6.1, U1.10 (IN5M)
/IN5_P: C5.1, U1.9 (IN5P)
/IN6_N: C14.1, U1.12 (IN6M)
/IN6_P: C13.1, U1.11 (IN6P)
/IN7_N: C8.1, U1.14 (IN7M)
/IN7_P: C7.1, U1.13 (IN7P)
/IN8_N: C16.1, U1.16 (IN8M)
/IN8_P: C15.1, U1.15 (IN8P)
AVDD: C26.1, C29.1, C32.1, L2.2, U1.19 (AVDD18), U1.24 (AVDD18), U1.62 (AVDD18)
AVDD3V3: L3.2, U1.18 (AVDD3)
DVDD: C27.1, C30.1, C33.1, C35.2, C38.1, L2.1, U1.28 (DVDD18), U1.30 (DVDD18), U1.51 (DVDD18), U2.2 (VO)
DVDD3V3: C24.2, C28.1, C36.2, C37.1, L1.1, L3.1, R16.1, R17.1, R18.1, U2.3 (VI), U3.2 (VO)
GND: C17.1, C18.2, C19.2, C22.1, C23.1, C24.1, C25.1, C27.2, C28.2, C30.2, C31.2, C33.2, C34.1, C35.1, C36.1, C37.2, C38.2, D1.2 (A), J1.1, J1.4, J1.7, J2.1, J2.4, J2.7, J3.1, J3.4, J3.7, J4.1, J4.4, J4.7, J5.2, J6.2, J7.1, J7.4, J7.7, J8.8, J9.2, J10.A1, J10.A4, J10.A7, J10.A12, J10.A15, J10.A18, J10.B1, J10.B4, J10.B7, J10.B12, J10.B15, J10.B18, J11.1, J11.2, J11.5, J11.6, JP1.1 (A), M1.1, M2.1, M3.1, M4.1, R11.1, R12.2, R13.2, R14.1, R15.1, R19.1, U1.29 (DVSS), U1.52 (DVSS), U2.1 (GND), U3.1 (GND)
GNDA: C26.2, C29.2, C32.2, JP1.2 (B), U1.20 (AVSS), U1.23 (AVSS), U1.61 (AVSS), U1.63 (AVSS), U1.65 (AVSS)
unnamed: C1.2, J1.6, R1.1
unnamed: C2.2, J1.5, R1.2
unnamed: C3.2, J2.6, R3.1
unnamed: C4.2, J2.5, R3.2
unnamed: C5.2, J3.6, R5.1
unnamed: C6.2, J3.5, R5.2
unnamed: C7.2, J4.6, R7.1
unnamed: C8.2, J4.5, R7.2
unnamed: C9.2, J1.3, R2.1
unnamed: C10.2, J1.2, R2.2
unnamed: C11.2, J2.3, R4.1
unnamed: C12.2, J2.2, R4.2
unnamed: C13.2, J3.3, R6.1
unnamed: C14.2, J3.2, R6.2
unnamed: C15.2, J4.3, R8.1
unnamed: C16.2, J4.2, R8.2
unnamed: C17.2, J5.1, U1.17 (VCM)
unnamed: C18.1, L1.2, R9.2, R10.2
unnamed: C19.1, J6.1, U1.64 (VCM)
unnamed: C23.2, J10.1, J10.2, J10.3, J10.4, J10.5, J10.6, J10.7, J10.8, R19.2
unnamed: J8.1, R11.2, U1.59 (PDN)
unnamed: J8.5, R13.1, U1.57 (RESET)
unnamed: J8.7, R16.2, U1.56 (SCLK)
unnamed: J8.6, R17.2, U1.55 (SDATA)
unnamed: J8.2, U1.53 (SDOUT)
unnamed: J8.4, R18.2, U1.54 (SEN)
unnamed: J8.3, R12.1, U1.58 (SYNC)
unnamed: C22.2, J9.1, U1.25 (VREF_IN)
VCC: C25.2, C31.1, C34.2, D1.1 (K), J11.3, J11.4, U3.3 (VI)

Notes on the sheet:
Bias1
Bias2
POWER INPUT
MOUNTING HOLES
1V8
3V3

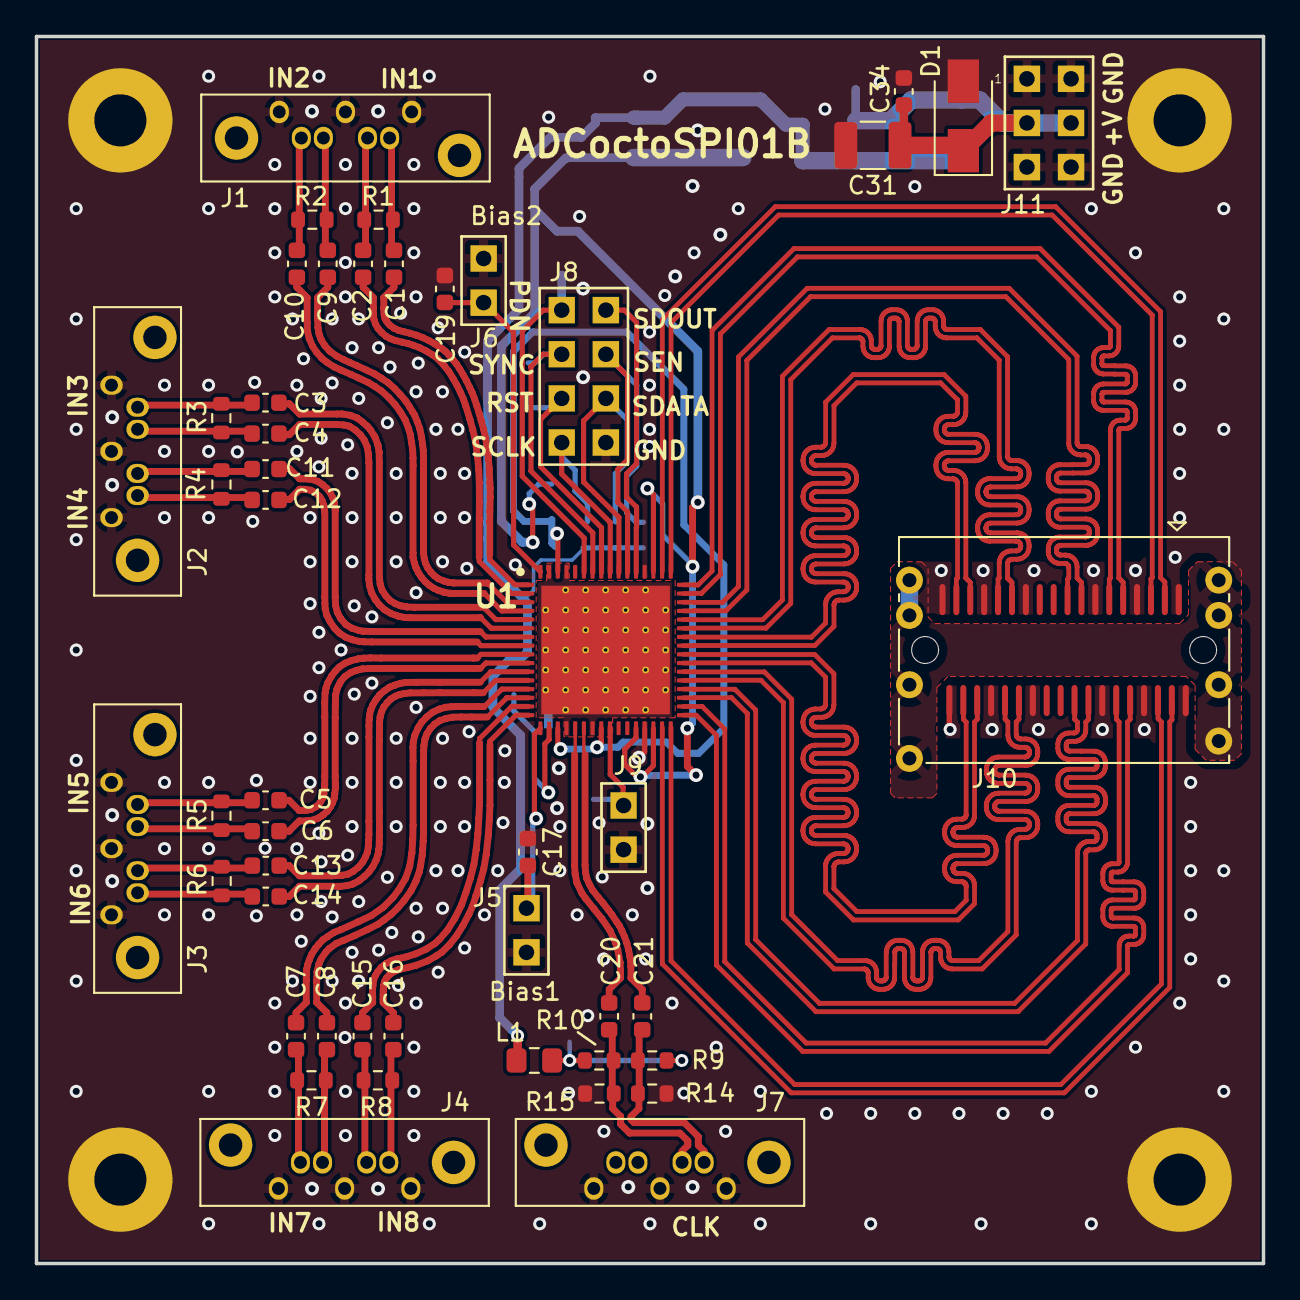
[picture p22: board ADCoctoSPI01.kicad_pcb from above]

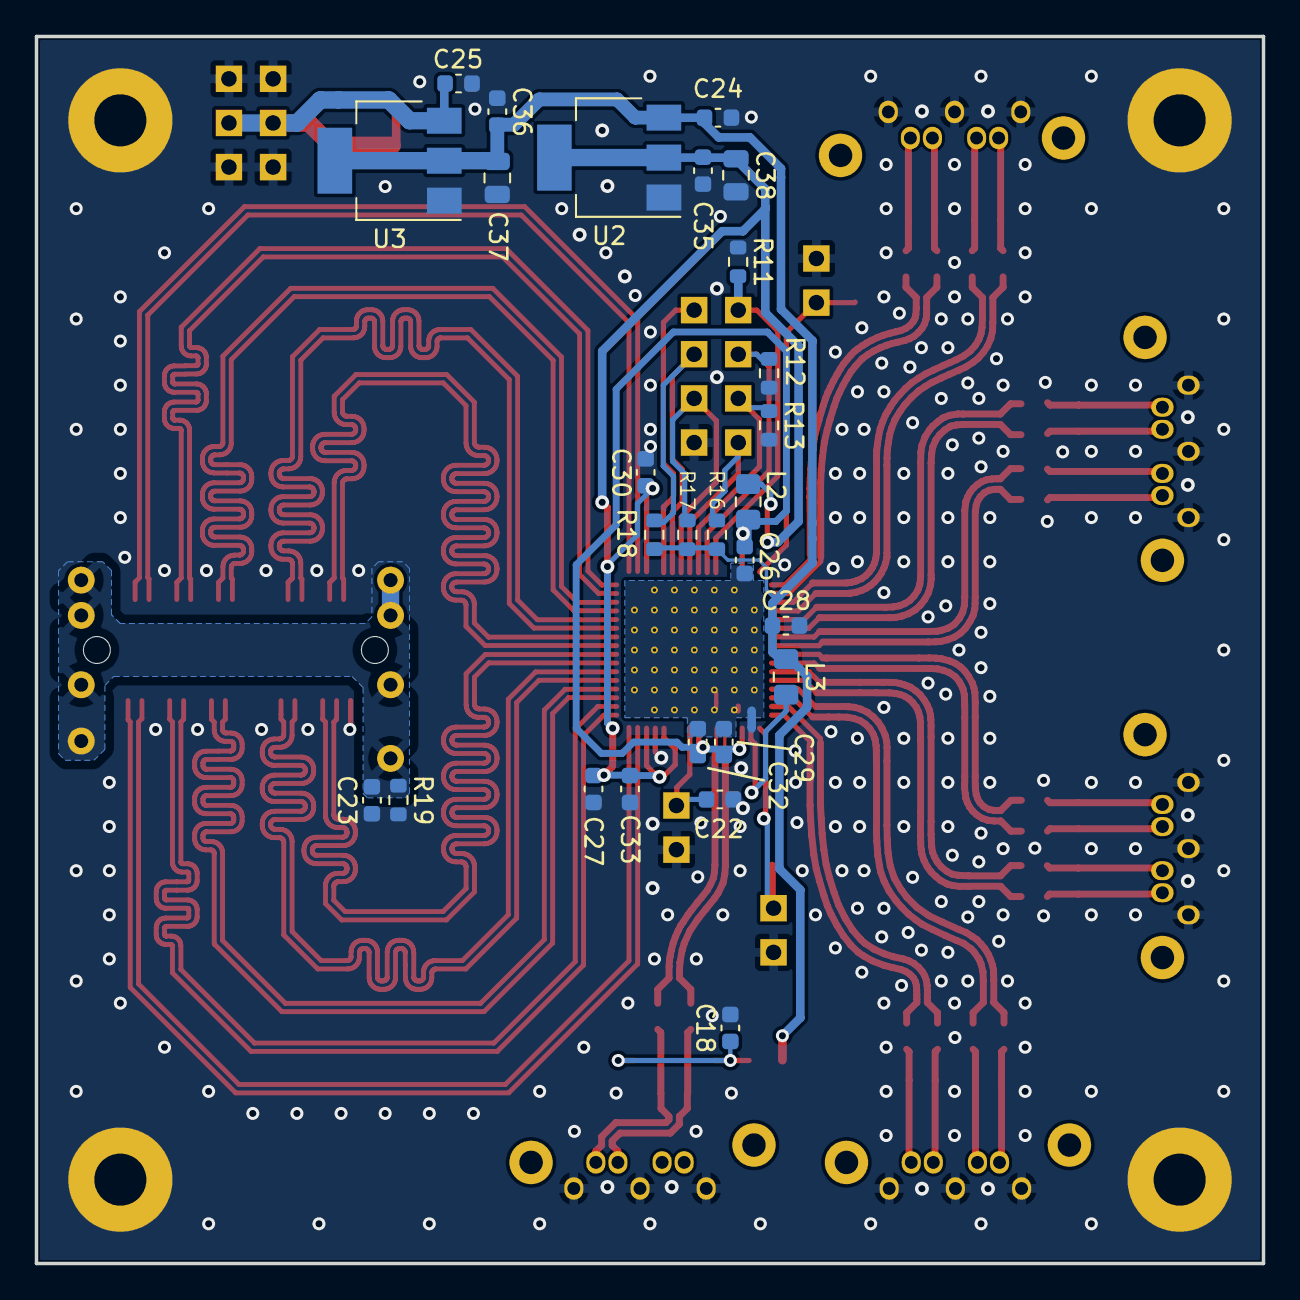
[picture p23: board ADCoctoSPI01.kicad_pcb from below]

Board: 2 copper layers, 70.6 x 70.6 mm, 80 parts (28 on the bottom side), 75 nets.

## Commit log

2020-06-15 Adding new ADC design.
    [ADCoctoSPI01A.kicad_pcb, ADCoctoSPI01A.sch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]
2021-04-14 schematic title block update.
    [ADCoctoSPI01A.kicad_sch, ADCoctoSPI01A.sch]
2022-02-17 Repository cleanup Update of KiCAD project version to 6.0.1.
    [ADCoctoSPI01A.kicad_pcb, ADCoctoSPI01A.kicad_sch]
2022-03-11 Add a link to schematics.
    [ADCoctoSPI01A.kicad_sch]
2022-03-24 Update footprints.
    [ADCoctoSPI01A.kicad_pcb, ADCoctoSPI01A.kicad_sch]
2022-03-25 Update mini SAS connector footprint to up to date footprint from KiCAD library.
    [ADCoctoSPI01A.kicad_pcb, ADCoctoSPI01A.kicad_sch]
2022-03-25 Repair footprint #2.
    [ADCoctoSPI01A.kicad_pcb]
2022-03-26 Update miniSAS connector footprint.
    [ADCoctoSPI01A.kicad_pcb]
2022-04-05 Prejmenovani Kicad projektu
    [ADCoctoSPI01B.kicad_pcb, ADCoctoSPI01B.kicad_sch]
2022-04-05 Edit PCB
    [ADCoctoSPI01B.kicad_pcb, ADCoctoSPI01B.kicad_sch]
2022-04-05 Remove KiCAD backups and attempt to fix that by introducing a gitignore file.
2022-04-06 Edit footprints + 3d models
    [ADCoctoSPI01B.kicad_pcb, ADCoctoSPI01B.kicad_sch]
2022-04-06 new workflows/kicad_outputs.yml
2022-04-06 Update actions products
    [ADCoctoSPI01B-B_Adhesive.dxf, ADCoctoSPI01B-B_Courtyard.dxf, ADCoctoSPI01B-B_Cu.dxf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]
2022-04-06 Edit footprint AFE5801
    [ADCoctoSPI01B.kicad_pcb, ADCoctoSPI01B.kicad_sch]
2022-04-07 Edit bom
    [ADCoctoSPI01B.kicad_pcb, ADCoctoSPI01B.kicad_sch]
2022-05-17 uprava layoutu
    [ADCoctoSPI01B.kicad_pcb]
2022-05-18 rozdeleni VSSA a VSSD
    [ADCoctoSPI01B.kicad_pcb, ADCoctoSPI01B.kicad_sch]
2022-05-25 Příprava podkladů pro osazení
    [ADCoctoSPI01B.kicad_pcb, ADCoctoSPI01B.kicad_sch]
2022-06-28 cleanup traces in schematics.
    [ADCoctoSPI01B.kicad_sch]
2022-08-21 Cleanup schematics.
    [ADCoctoSPI01B.kicad_sch]
2025-10-24 Update to KiCADv9.
    [ADCoctoSPI01.kicad_pcb, ADCoctoSPI01.kicad_sch, ADCoctoSPI01B.kicad_pcb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]
